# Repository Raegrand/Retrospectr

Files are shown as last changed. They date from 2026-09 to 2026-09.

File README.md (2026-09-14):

# Retrospectr

**Retrospectr** is an open-source hardware project powered by the **Seeed Studio XIAO ESP32-C3**, featuring a compact TFT display, interactive controls, microSD storage, and portable battery support.

The 3D-printable enclosure is a modified remix based on the **CYD Retro Mini TV by DynaMight1124**.

---

## 🛠️ Hardware Specifications

| Component | Specification |
| --- | --- |
| **Microcontroller** | Seeed Studio XIAO ESP32-C3 — RISC-V 32-bit single-core, Wi-Fi & Bluetooth 5 |
| **Display** | 1.69-inch TFT, ST7789 driver, 240 × 280 resolution |
| **Rotary Input** | ALPS Rotary Encoder with push button |
| **Push Button** | 6 × 6 × 10 mm tactile push button |
| **Storage** | MicroSD card reader, supporting 16 GB SDHC |
| **Battery** | 1S 3.7 V, 1,200 mAh LiPo battery |

---

## 📁 Repository Structure

```text
Retrospectr/
├── 3DDesign/
│   └── Mechanical CAD files and 3D-printable enclosure designs
│
├── src/
│   └── Python tools for image and Bible text processing
│
├── main/
│   └── Main firmware and ESP32-C3 configuration
│
├── gallery/
│   └── Gallery images (.bin) and associated text (.txt)
│
└── docs/
    └── Project documentation and SD card information
```

### Directory Details

* **`3DDesign/`** — Contains the mechanical CAD files and 3D-printable enclosure designs.
* **`src/`** — Contains Python utilities for image processing, image-to-RGB565 conversion, batch conversion, and Bible text processing.
* **`main/`** — Contains the main firmware and hardware configuration used by the ESP32-C3.
* **`gallery/`** — Contains the image and text files used by the Retrospectr gallery.
* **`docs/`** — Contains additional project documentation and SD card information.

---

## 🚀 Getting Started

### 1. Clone the Repository

```bash
git clone https://github.com/your-username/Retrospectr.git
cd Retrospectr
```

### 2. Prepare the Enclosure

Navigate to the [`3DDesign/`](./3DDesign/) directory and select the appropriate CAD files for 3D printing.

The enclosure is a modified remix of the **CYD Retro Mini TV by DynaMight1124**.

### 3. Prepare the Gallery

Gallery content consists of matching numbered `.bin` and `.txt` files:

```text
gallery/
├── 1.bin
├── 1.txt
├── 2.bin
├── 2.txt
└── ...
```

The `.bin` file contains the RGB565 image data, while the `.txt` file contains the corresponding text.

Refer to [`gallery/README.md`](./gallery/README.md) for the file naming requirements.

### 4. Prepare the Firmware

The main firmware is located in [`main/`](./main/).

Refer to [`main/README.md`](./main/README.md) for the firmware configuration and hardware wiring.

### 5. Prepare Additional Data

Refer to [`src/README.md`](./src/README.md) for the Python utilities used to prepare gallery images and Bible text for the SD card.

---

## 🔧 Project Features

Retrospectr combines a compact custom enclosure with an ESP32-C3-based embedded system, providing:

* 📺 Compact ST7789 TFT display
* 🎛️ Rotary encoder navigation
* 🔘 Physical push-button input
* 💾 MicroSD-based storage
* 🔋 Portable LiPo battery power
* 🖼️ Image gallery
* 📖 Bible text support
* 🖨️ 3D-printable custom enclosure
* 🧩 Open-source hardware and software

---

## 📄 License

### Firmware & Code

The firmware and software are **open-source**. You are free to fork, modify, and build upon the software.

### 3D Design Files

The 3D enclosure design is licensed under the **Creative Commons Attribution-NonCommercial 4.0 International (CC BY-NC 4.0)** license.

The enclosure is a modification of the **CYD Retro Mini TV by DynaMight1124**. You are free to share and remix the design for **non-commercial purposes**, provided that appropriate attribution is given to the original creator.

---

## 🙏 Credits

* **Seeed Studio** — XIAO ESP32-C3
* **DynaMight1124** — Original CYD Retro Mini TV enclosure design
* **Retrospectr** — Hardware modifications, firmware, and project development

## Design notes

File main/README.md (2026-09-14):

# Retrospectr — Main Firmware

This folder contains the main firmware and hardware configuration for the **Retrospectr** ESP32-C3 system.

The firmware is designed for the **Seeed Studio XIAO ESP32-C3** and interfaces with the TFT display, rotary encoder, push button, and microSD card.

---

## 🛠️ Hardware Configuration

### ST7789 TFT Display

| TFT Pin | XIAO ESP32-C3 GPIO | Description |
| --- | ---: | --- |
| CS | GPIO 21 | Chip Select |
| DC | GPIO 6 | Data / Command |
| RST | — | Not used |
| BL | GPIO 7 | Backlight |
| VCC | 3.3V | Power |
| GND | GND | Ground |
| SCK | SPI SCK | SPI clock |
| MOSI | SPI MOSI | SPI data |

The display configuration uses a **280 × 240** display size in the firmware.

> **Note:** The SPI SCK and MOSI GPIO numbers are not explicitly defined in the provided `config.h`, so they are not assigned specific GPIO numbers here.

### 💾 MicroSD Card Reader

| SD Pin | XIAO ESP32-C3 GPIO | Description  |
| --- | ---: | --- |
| CS | GPIO 4 | Chip Select  |
| SCK | SPI SCK | SPI clock |
| MOSI | SPI MOSI | SPI data out |
| MISO | SPI MISO | SPI data in  |
| VCC | 3.3V | Power |
| GND | GND | Ground |

The microSD chip-select pin is configured as **GPIO 4**.

### 🎛️ ALPS Rotary Encoder

| Encoder Pin | XIAO ESP32-C3 GPIO | Description |
| --- | ---: | --- |
| CLK | GPIO 2 | Rotary encoder clock |
| DT | GPIO 3 | Rotary encoder data  |
| SW | GPIO 20 | Encoder push button  |
| VCC | 3.3V | Power |
| GND | GND | Ground |

The encoder GPIO assignments are defined as CLK = GPIO 2, DT = GPIO 3, and SW = GPIO 20.

### 🔘 Extra Push Button

| Button Pin | XIAO ESP32-C3 GPIO | Description  |
| --- | ---: | --- |
| Signal | GPIO 5 | Button input |
| GND | GND | Ground |

The extra push button uses **GPIO 5**.

---

## 📌 GPIO Summary

| Function | GPIO |
| --- | ---: |
| TFT CS | 21 |
| TFT DC | 6 |
| TFT RST | Not used |
| TFT Backlight | 7 |
| SD CS | 4 |
| Rotary CLK | 2 |
| Rotary DT | 3 |
| Rotary SW | 20 |
| Extra Button  | 5 |

---

## 🖥️ Display Configuration

| Parameter | Value |
| --- | --- |
| **Driver** | ST7789 |
| **Width** | 280 pixels |
| **Height** | 240 pixels |
| **Backlight** | GPIO 7 |

---

## 💾 SD Card Content

The Retrospectr SD card stores gallery images and their corresponding text files.

Gallery files use matching numerical filenames:

```text
SD Card/
├── 1.bin
├── 1.txt
├── 2.bin
├── 2.txt
├── 3.bin
├── 3.txt
└── ...
```

For more information about gallery file preparation and naming, see [`../gallery/README.md`](../gallery/README.md).

---

## 🔧 Firmware

The firmware in this directory is the main program uploaded to the **XIAO ESP32-C3**.

Before uploading the firmware:

1. Connect the required hardware according to the wiring tables above.
2. Prepare the SD card with the required gallery files.
3. Verify the display and input connections.
4. Build and upload the firmware to the XIAO ESP32-C3.

---

## 📁 Related Directories

| Directory | Purpose |
| --- | --- |
| [`../3DDesign/`](../3DDesign/) | Mechanical CAD and enclosure design |
| [`../src/`](../src/) | Image and Bible text processing utilities |
| [`../gallery/`](../gallery/) | Gallery `.bin` and `.txt` files |
| [`../docs/`](../docs/) | Project documentation |

---

## 📄 License

The firmware and software in this directory are **open-source**. You are free to fork, modify, and build upon the code.

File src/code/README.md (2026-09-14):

# Image & Data Processing Tools

This folder contains Python utilities used to prepare images and Bible text for the Retrospectr ESP32-C3 system.

## 📦 Requirements

Install the required Python package:

```bash
pip install Pillow
```

The scripts use Python's standard libraries along with **Pillow (PIL)** for image processing.

---

## 🛠️ Scripts

### `filter.py`

Applies a vintage/sepia color effect to images contained in a ZIP file and produces a new ZIP file.

The filter:

* Converts images to RGB.
* Applies a sepia/vintage color transformation.
* Blends the effect with the original image.
* Slightly reduces contrast.
* Preserves the original DPI when available.
* Supports `.png`, `.jpg`, and `.jpeg` images.
* Removes macOS hidden files from the output.

**Usage:**

```bash
python filter.py input.zip output.zip
```

Example:

```bash
python filter.py original_images.zip filtered_images.zip
```

---

### `png2bin.py`

Converts a single PNG image into a raw **RGB565 `.bin` file** for use with the TFT display.

The image is converted to RGB565 using:

* 5 bits for Red
* 6 bits for Green
* 5 bits for Blue

The script supports both little-endian and big-endian output.

**Usage:**

```bash
python png2bin.py input.png output.bin
```

For big-endian output:

```bash
python png2bin.py input.png output.bin --swap
```

---

### `zip2bin.py`

Batch-converts all PNG images inside a ZIP file into RGB565 `.bin` files.

The original filename is retained, with the `.png` extension replaced by `.bin`.

**Usage:**

```bash
python zip2bin.py images.zip
```

Specify an output directory:

```bash
python zip2bin.py images.zip -o output
```

For big-endian output:

```bash
python zip2bin.py images.zip -o output --swap
```

---

### `slice.py`

Processes an Indonesian TB Bible text file and separates it into individual chapter files.

The script:

* Reads `indo_tb (1).txt`.
* Detects the Bible book, chapter, and verse using a regular expression.
* Creates a folder for each Bible book.
* Creates a separate `.txt` file for each chapter.
* Formats each verse as:

```text
1. Verse text
2. Verse text
3. Verse text
```

The resulting structure is suitable for copying to the Retrospectr SD card.
**Usage:**

Place the source Bible file in the same directory as `slice.py`, then run:

```bash
python slice.py
```

The generated structure will look similar to:

```text
Kejadian/
├── 1.txt
├── 2.txt
├── 3.txt
└── ...

Keluaran/
├── 1.txt
├── 2.txt
└── ...
```

---

## 🔄 Recommended Image Workflow

For preparing gallery images for Retrospectr:

```text
Original Images
      │
      ▼
  filter.py
      │
      ▼
Filtered PNG Images
      │
      ▼
  zip2bin.py
      │
      ▼
RGB565 .bin Files
      │
      ▼
   SD Card
      │
      ▼
  Retrospectr
```

For a single image, `png2bin.py` can be used instead of `zip2bin.py`.

## 📋 Quick Reference

| Script | Input | Output | Purpose |
| --- | --- | --- | --- |
| `filter.py`  | ZIP of images | ZIP of filtered PNGs | Apply vintage color effect |
| `png2bin.py` | PNG | RGB565 `.bin` | Convert one image |
| `zip2bin.py` | ZIP of PNGs | `.bin` files | Batch image conversion |
| `slice.py` | Bible `.txt`  | Book/chapter `.txt` files | Prepare Bible text for SD card |

## ⚠️ Notes

* `png2bin.py` and `zip2bin.py` generate raw RGB565 binary data.
* Use `--swap` if the target TFT configuration requires big-endian RGB565 data.
* `slice.py` expects the input file to be named **`indo_tb (1).txt`** and located in the same directory as the script.
* Make sure the generated files match the format expected by the firmware before copying them to the SD card.

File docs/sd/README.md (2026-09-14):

# Retrospectr — SD Card Structure

This folder contains the files and folder structure required by the Retrospectr firmware.

> ⚠️ **Important:** Do not change the folder names, file names, or file formats. The firmware expects the SD card data to follow the structure described below.

---

## 📁 SD Card Structure

The SD card must contain the following folders:

```text
SD Card/
├── Gallery/
│   ├── 1.bin
│   ├── 1.txt
│   ├── 2.bin
│   ├── 2.txt
│   └── ...
│
└── Bible/
    ├── Kejadian/
    │   ├── 1.txt
    │   ├── 2.txt
    │   └── ...
    │
    ├── Keluaran/
    │   ├── 1.txt
    │   ├── 2.txt
    │   └── ...
    │
    └── ...
```

## 🖼️ Gallery

The `Gallery/` folder contains the images and corresponding text displayed by Retrospectr.

Each item must contain a matching `.bin` image file and `.txt` text file:

```text
Gallery/
├── 1.bin
├── 1.txt
├── 2.bin
├── 2.txt
└── ...
```

### File Requirements

* Image files must use the **`.bin`** format.
* Text files must use the **`.txt`** format.
* Both files must use the **same number**.
* Numbering starts from **`1`**.
* Keep the numbering sequential.
* Do not rename `Gallery/`.

For example:

```text
1.bin  → Image 1
1.txt  → Text for Image 1

2.bin  → Image 2
2.txt  → Text for Image 2
```

See [`../gallery/README.md`](../gallery/README.md) for more information.

---

## 📖 Bible

The `Bible/` folder contains the Indonesian Bible text organized by **book and chapter**.

Each Bible book must have its own folder:

```text
Bible/
├── Kejadian/
├── Keluaran/
├── Imamat/
└── ...
```

Each chapter is stored as a numbered `.txt` file:

```text
Bible/
└── Kejadian/
    ├── 1.txt
    ├── 2.txt
    ├── 3.txt
    └── ...
```

The chapter number must correspond to the chapter.

For example:

```text
Kejadian/1.txt  → Kejadian Chapter 1
Kejadian/2.txt  → Kejadian Chapter 2
Kejadian/3.txt  → Kejadian Chapter 3
```

---

## ⚠️ Do Not Change the Structure

The following must remain unchanged:

| Item | Required Format |
| --- | --- |
| **Gallery folder** | `Gallery/` |
| **Gallery images** | `1.bin`, `2.bin`, `3.bin`, ... |
| **Gallery text** | `1.txt`, `2.txt`, `3.txt`, ... |
| **Bible folder** | `Bible/` |
| **Bible book folders** | One folder per book |
| **Bible chapters** | `1.txt`, `2.txt`, `3.txt`, ... |
| **Image format** | RGB565 `.bin` |
| **Text format** | `.txt` |

Changing the folder names or expected file formats may cause the firmware to **fail to find or load the corresponding data**.

---

## 📌 SD Card Preparation

Before inserting the SD card into Retrospectr:

1. Format the SD card using the required filesystem.
2. Create the required folders.
3. Copy the gallery files into `Gallery/`.
4. Copy the Bible book folders into `Bible/`.
5. Verify that filenames and folder names exactly match the required structure.
6. Insert the SD card into Retrospectr.

Keep the SD card structure consistent with this README when adding or replacing content.

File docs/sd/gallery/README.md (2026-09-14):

# Gallery

This folder contains the images and corresponding text displayed by Retrospectr.

## 📁 File Format

Each gallery item consists of **two files** with the same number:

```text
gallery/
├── 1.bin
├── 1.txt
├── 2.bin
├── 2.txt
├── 3.bin
├── 3.txt
└── ...
```

* **`.bin`** — Image file to be displayed on the TFT.
* **`.txt`** — Text associated with the image.
* Files must use **matching numbers** so the image and text are paired correctly.

### Example

```text
1.bin  →  Image 1
1.txt  →  Text for Image 1

2.bin  →  Image 2
2.txt  →  Text for Image 2

3.bin  →  Image 3
3.txt  →  Text for Image 3
```

## ⚠️ Naming Rules

* Use numbers starting from **`1`**.
* The `.bin` and `.txt` files must have the **same number**.
* Do not use spaces or additional characters in the filenames.
* Keep the numbering sequential.

**Valid:**

```text
1.bin
1.txt
2.bin
2.txt
3.bin
3.txt
```

**Invalid:**

```text
image1.bin
1_image.bin
1.txt
2.bin
3.txt
```

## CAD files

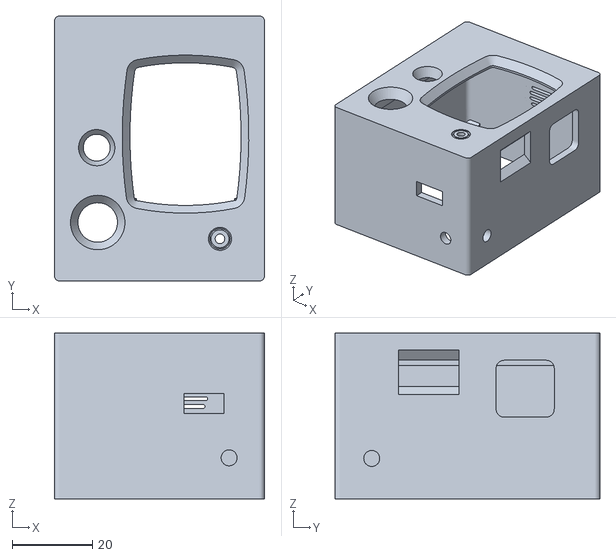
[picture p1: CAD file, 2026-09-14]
3DDesign/MainBody.stl
52.4 x 66.0 x 41.2

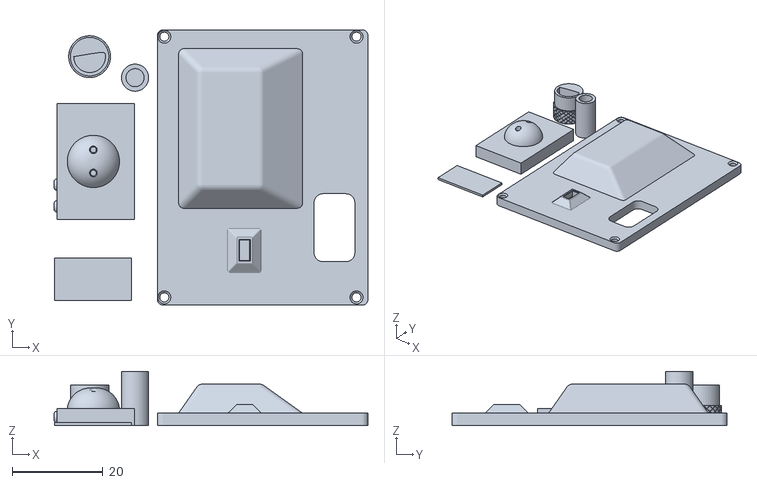
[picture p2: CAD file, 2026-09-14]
3DDesign/CoverandAccecories.stl
69.2 x 60.8 x 12.0

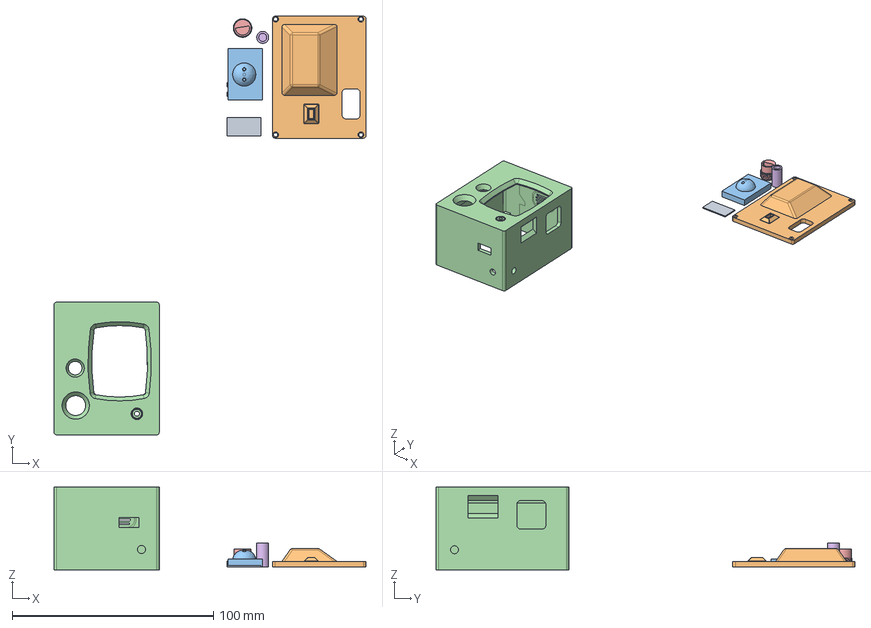
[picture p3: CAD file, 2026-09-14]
3DDesign/Casing design.step
155.2 x 208.3 x 41.2 mm

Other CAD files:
3DDesign/Casing design.f3z

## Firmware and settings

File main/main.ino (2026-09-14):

#include "src/header/config.h"
#include "src/header/encoder.h"
#include "src/header/storage.h"
#include "src/header/display.h"
#include "src/header/power.h"
#include "src/header/menu.h"
#include <Preferences.h>
#include <esp_random.h>
#include "esp_sleep.h"
#include <SD.h>

int totalImages = 0;
RTC_DATA_ATTR int currentImage = 1;

bool isScreenOn = true;
unsigned long lastActivityTime = 0;
unsigned long lastImageChangeTime = 0;
int sleepTimeoutMinutes = 3;
int textSpeedMs = 300;

void setup() {
  Serial.begin(115200);
  delay(1000);

  sleepTimeoutMinutes = loadSleepTimeout();
  textSpeedMs = loadTextSpeed();

  systemStartUp();
  
  lastActivityTime = millis();
  lastImageChangeTime = millis();

  if (totalImages > 0) {
    currentImage = (esp_random() % totalImages) + 1;
    drawBinByIndex(currentImage); 
  } else {
    showMessage("No images", ST77XX_YELLOW);
  }
}

void loop() {
  if (totalImages == 0 || !isScreenOn) return;

  // 1. Extra Button -> Return to / Open Main Menu
  if (isExtraButtonPressed()) {
    lastActivityTime = millis();

    MenuChoice choice = openMainMenu();

    switch (choice) {
      case MENU_GALLERY:
        // Return to viewing current gallery image
        drawBinByIndex(currentImage);
        break;

      case MENU_BIBLE:
      {
        String languageFolder = openLanguageMenu();
        if (languageFolder.length() == 0) { drawBinByIndex(currentImage); break; }

        int testamentChoice = openTestamentMenu();
        if (testamentChoice == 0) { drawBinByIndex(currentImage); break; }
        
        String startPath = "/" + languageFolder;
        if (!SD.exists(startPath)) startPath = "/Bible/" + languageFolder; 

        if (!SD.exists(startPath)) {
          showMessage("Folder Missing!", ST77XX_RED);
          delay(1500); drawBinByIndex(currentImage); break;
        }

        String selectedFile = openBibleBrowser(startPath, testamentChoice);
        
        if (selectedFile.length() > 0) {
          bool reading = true;

          // CONTINUOUS CHAPTER LOOP
          while (reading) {
            String headerText = selectedFile;
            
            if (headerText.startsWith(startPath)) headerText = headerText.substring(startPath.length());
            if (headerText.startsWith("/")) headerText = headerText.substring(1);
            headerText.replace('/', ' - '); 

            // readPaginatedText returns true if you hit "next" on the final page
            bool advanceToNext = readPaginatedText(selectedFile, headerText);
            
            reading = false; // Assume we are stopping

            if (advanceToNext) {
              // Extract the number from the file name (e.g. Chapter_1.txt -> 1)
              int dotIdx = selectedFile.lastIndexOf('.');
              if (dotIdx != -1) {
                int numEnd = dotIdx;
                int numStart = dotIdx - 1;
                while (numStart >= 0 && isDigit(selectedFile[numStart])) {
                  numStart--;
                }
                numStart++;
                
                if (numStart < numEnd) {
                  String numStr = selectedFile.substring(numStart, numEnd);
                  int nextNum = numStr.toInt() + 1;
                  
                  // Construct new path (e.g. Chapter_2.txt)
                  String nextPath = selectedFile.substring(0, numStart) + String(nextNum) + selectedFile.substring(numEnd);
                  
                  // Automatically load the next chapter if it exists
                  if (SD.exists(nextPath)) {
                    selectedFile = nextPath;
                    reading = true; 
                  }
                }
              }
            }
          } // End while(reading)
        }
        
        drawBinByIndex(currentImage);
      }
      break;

      case MENU_SETTINGS:
        // Open Settings configuration menu
        openSettingsSubmenu();
        // Reload settings values in case they were updated
        textSpeedMs = loadTextSpeed();
        sleepTimeoutMinutes = loadSleepTimeout();
        drawBinByIndex(currentImage);
        break;
    }

    lastActivityTime = millis();
    lastImageChangeTime = millis();
  }

  // 2. Rotary Encoder Scroll (Gallery Navigation)
  int scroll = getEncoderScroll();
  if (scroll != 0) {
    lastActivityTime = millis();
    currentImage += scroll;
    
    if (currentImage < 1) currentImage = totalImages; 
    if (currentImage > totalImages) currentImage = 1; 
    
    drawBinByIndex(currentImage); 
    lastImageChangeTime = millis();
  }

  // 3. Encoder Button Click -> View Scripture Text for Current Image
  if (isButtonPressed()) {
    lastActivityTime = millis();
    readTextFile(currentImage, textSpeedMs);
    drawBinByIndex(currentImage);
    
    lastActivityTime = millis();
    lastImageChangeTime = millis();
  }

  // 4. Auto-Advance (Slideshow every 15 sec)
  if (millis() - lastImageChangeTime >= 15000) {
    currentImage++;
    if (currentImage > totalImages) currentImage = 1; 
    
    drawBinByIndex(currentImage); 
    lastImageChangeTime = millis();
  }

  // 5. Inactivity Deep Sleep Check
  unsigned long timeoutMs = (unsigned long)sleepTimeoutMinutes * 60000;
  if (millis() - lastActivityTime >= timeoutMs) {
    enterDeepSleep();
  }
}

void systemStartUp() {
  Serial.println("\n--- SYSTEM WAKE / START UP ---");

  initEncoder();

  if (!initSD()) {
    Serial.println("SD Card Failed!");
    return;
  }
  Serial.println("SD Card OK!");

  initDisplay();

  // 1. Play Analog TV Static Animation
  showTVStatic(1000); 

  // 2. 15% Chance Scripture Startup Trigger
  if ((esp_random() % 100) < 15) {
    Serial.println("Startup Event: Displaying Random Scripture!");
    readRandomScripture("/media/scr.txt", textSpeedMs, "/media/dailyBg.bin");
  }

  totalImages = countTotalImages();
  Serial.print("Total images found: ");
  Serial.println(totalImages);
}

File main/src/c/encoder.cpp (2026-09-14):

#include "../header/encoder.h"
#include "../header/config.h"

// Variables modified by the interrupt must be declared 'volatile'
volatile int encoderCount = 0;
volatile uint8_t prev_state = 0;

// Quadrature state machine table. 
// Valid forward movements = 1, backward = -1. Invalid jumps (noise) = 0.
static const int8_t encoder_table[] = {0, -1, 1, 0, 1, 0, 0, -1, -1, 0, 0, 1, 0, 1, -1, 0};

void IRAM_ATTR readEncoderISR() {
  // Shift the previous state to the left
  prev_state <<= 2;
  
  // Read current pin states
  uint8_t clk = digitalRead(ROTARY_CLK);
  uint8_t dt = digitalRead(ROTARY_DT);
  
  // Combine into a 2-bit number and add to previous state
  prev_state |= ((clk << 1) | dt);
  
  // Look up the score in the table and add it to the total
  encoderCount += encoder_table[prev_state & 0x0F];
}

void initEncoder() {
  pinMode(ROTARY_CLK, INPUT_PULLUP);
  pinMode(ROTARY_DT, INPUT_PULLUP);
  pinMode(ROTARY_SW, INPUT_PULLUP);
  pinMode(EXTRA_BTN, INPUT_PULLUP); 
  
  // Initialize starting state
  uint8_t clk = digitalRead(ROTARY_CLK);
  uint8_t dt = digitalRead(ROTARY_DT);
  prev_state = (clk << 1) | dt;

  // Track EVERY change on BOTH pins to map the exact physical movement
  attachInterrupt(digitalPinToInterrupt(ROTARY_CLK), readEncoderISR, CHANGE);
  attachInterrupt(digitalPinToInterrupt(ROTARY_DT), readEncoderISR, CHANGE);
}

int getEncoderScroll() {
  int direction = 0;
  
  // Most KY-040 encoders register 4 internal state changes per physical "click"
  if (encoderCount >= 4) {
    direction = 1;
    encoderCount -= 4; // Subtract rather than reset to 0 to preserve fast scrolling
  } else if (encoderCount <= -4) {
    direction = -1;
    encoderCount += 4; 
  }
  
  return direction;
}

bool isButtonPressed() {
  if (digitalRead(ROTARY_SW) == LOW) {
    delay(50); 
    if (digitalRead(ROTARY_SW) == LOW) {
      while(digitalRead(ROTARY_SW) == LOW) { delay(10); } 
      return true;
    }
  }
  return false;
}

bool isExtraButtonPressed() {
  if (digitalRead(EXTRA_BTN) == LOW) {
    delay(50); 
    if (digitalRead(EXTRA_BTN) == LOW) {
      while(digitalRead(EXTRA_BTN) == LOW) { delay(10); } 
      return true;
    }
  }
  return false;
}

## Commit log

2026-09-11 V1.1 button interupt, starting animation, deepsleep, text display optimization
    [controller_a_and_b_button.stl, controller_bottom.stl, controller_dpad.stl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]
2026-09-14 V2.0 Finished product
    [Casing design.f3z, Casing design.step, CoverandAccecories.stl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]
